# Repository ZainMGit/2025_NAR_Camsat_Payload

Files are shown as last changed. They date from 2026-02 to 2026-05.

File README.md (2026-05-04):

# 2025_NAR_CanSat_Payload
Download KiCAD_Camsat_PCB as a zip file and then open the project file within KiCAD to get the most up to date version of the pcb.

microsd pin orientation: 
-top view with pins pointing towards person and L to R- 
GND, VCC, MISO, MOSI, Sck, cs

9dof board
black wire - GND
Red - 3.3v 
blue- SDA
Yellow - SCL
order: BlaRBY

humidity - 
L to R with pins facing south
-GND, VCC, Signal

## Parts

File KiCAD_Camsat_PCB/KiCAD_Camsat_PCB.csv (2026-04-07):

Reference | Qty | Value | DNP | Exclude from BOM | Exclude from Board | Footprint | Datasheet
ADDR0 | 1 | JUMPER-SMT_3_1-NC_TRACE_SILK |  |  |  | KiCAD_Camsat_PCB:SMT-JUMPER_3_1-NC_TRACE_SILK
C1,C2,C26 | 3 | 2u2 |  |  |  | e-radionica.com footprinti:0603C
C3,C4 | 2 | 10uF |  |  |  | KiCAD_Camsat_PCB:0805-NO
C5,C6 | 2 | 0.1uF |  |  |  | KiCAD_Camsat_PCB:0603
C7,C18,C19,C21 | 4 | 100n |  |  |  | e-radionica.com footprinti:0603C
C8,C9,C13,C16,C20,C25 | 6 | 100nF |  |  |  | Capacitor_SMD:C_0603_1608Metric
C10,C12 | 2 | 10uF |  |  |  | Capacitor_SMD:C_0805_2012Metric
C11 | 1 | 4.7uF |  |  |  | Capacitor_SMD:C_0805_2012Metric
C17 | 1 | 22uF |  |  |  | Capacitor_SMD:C_1206_3216Metric
D1 | 1 | RED |  |  |  | KiCAD_Camsat_PCB:LED-0603
D2 | 1 | 1N4148 |  |  |  | KiCAD_Camsat_PCB:SOD-323
D3,D4,D9 | 3 | LESD5D5.0CT1G |  |  |  | Diode_SMD:D_SOD-523
I2C_PU0 | 1 | S_MODE |  |  |  | KiCAD_Camsat_PCB:SMT-JUMPER_3_2-NC_TRACE_SILK
J3 | 1 | 105017-0001 |  |  |  | Connector_USB:USB_Micro-B_Molex-105017-0001
J4 | 1 | 210-1S-1*3Ppin Gold-plated |  |  |  | Connector_PinHeader_2.54mm:PinHeader_1x03_P2.54mm_Vertical
J5 | 1 | DZ127R-11-02-25 |  |  |  | Connector_PinHeader_1.27mm:PinHeader_1x02_P1.27mm_Vertical
JP1 | 1 | SMD_JUMPER |  |  |  | e-radionica.com footprinti:SMD_JUMPER
JP9 | 1 | SMD-JUMPER-CONNECTED_TRACE_SLODERMASK |  |  |  | e-radionica.com footprinti:SMD-JUMPER-CONNECTED_TRACE_SLODERMASK
K1 | 1 | HYC77-TF09-200 |  |  |  | e-radionica.com footprinti:HYC77-TF09-200
LED0,SCX0,SDX0 | 3 | JUMPER-SMT_2_NC_TRACE_SILK |  |  |  | KiCAD_Camsat_PCB:SMT-JUMPER_2_NC_TRACE_SILK
LED1 | 1 | 0805G (Green) |  |  |  | LED_SMD:LED_0805_2012Metric
LED2 | 1 | FC-2012HRK-620D |  |  |  | LED_SMD:LED_0805_2012Metric
Q1,Q8 | 2 | 2N7002T-7-F |  |  |  | Package_TO_SOT_SMD:SOT-523
Q2,Q9 | 2 | SS8050-G_C164885 |  |  |  | Package_TO_SOT_SMD:SOT-23
Q3,Q4 | 2 | BSS138 |  |  |  | KiCAD_Camsat_PCB:SOT23-WIDE
R1 | 1 | 10k |  |  |  | e-radionica.com footprinti:0603R
R2,R25 | 2 | 2.2k |  |  |  | KiCAD_Camsat_PCB:0603
R3,R5,R6 | 3 | 10k |  |  |  | KiCAD_Camsat_PCB:0603
R4 | 1 | 1k |  |  |  | KiCAD_Camsat_PCB:0603
R7,R8,R26,R27 | 4 | 10K |  |  |  | KiCAD_Camsat_PCB:0805-NO
R9 | 1 | 10K |  |  |  | KiCAD_Camsat_PCB:_0805MP
R10 | 1 | 10k |  |  |  | Resistor_SMD:R_0805_2012Metric | ~
R11 | 1 | 47.5kΩ |  |  |  | Resistor_SMD:R_0805_2012Metric
R12 | 1 | 22.1kΩ |  |  |  | Resistor_SMD:R_0805_2012Metric
R13,R17,R18,R21,R22 | 5 | 10kΩ |  |  |  | Resistor_SMD:R_0805_2012Metric
R14,R24 | 2 | 22Ω |  |  |  | Resistor_SMD:R_0805_2012Metric
R15 | 1 | 5.1kΩ |  |  |  | Resistor_SMD:R_0805_2012Metric
R16 | 1 | 560Ω |  |  |  | Resistor_SMD:R_0805_2012Metric
R19,R20 | 2 | 0Ω |  |  |  | Resistor_SMD:R_0805_2012Metric
R23,R29 | 2 | 1kΩ |  |  |  | Resistor_SMD:R_0805_2012Metric
SW1,SW2 | 2 | PTS645SH50SMTR92LFS |  |  |  | Button_Switch_SMD:SW_SPST_PTS645Sx43SMTR92
U1 | 1 | ISM330DHCX |  |  |  | KiCAD_Camsat_PCB:LGA-14L
U2 | 1 | MIC5225-3.3 |  |  |  | KiCAD_Camsat_PCB:SOT23-5
U3 | 1 | SE5218 |  |  |  | e-radionica.com footprinti:SOT-23-5
U4 | 1 | TXB0104QPWRQ1 |  |  |  | e-radionica.com footprinti:TXB0104QPWRQ1
U5 | 1 | DHT11 |  |  |  | Sensor:Aosong_DHT11_5.5x12.0_P2.54mm | http://akizukidenshi.com/download/ds/aosong/DHT11.pdf
U7 | 1 | AMS1117-3.3_C347222 |  |  |  | Package_TO_SOT_SMD:SOT-223-3_TabPin2
U8 | 1 | ESP32-WROOM-32E(8MB) |  |  |  | PCM_Espressif:ESP32-WROOM-32E
U9 | 1 | CP2102N-A02-GQFN28R |  |  |  | Package_DFN_QFN:QFN-28-1EP_5x5mm_P0.5mm_EP3.35x3.35mm
U10 | 1 | BME280 |  |  |  | KiCAD_Camsat_PCB:BME280

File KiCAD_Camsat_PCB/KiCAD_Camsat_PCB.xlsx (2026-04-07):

Prj: | KiCAD_Camsat_PCB.csv |  |  |  | Board Qty: | 100
Co.: |  |  |  |  | Unit Cost: | $0.00
Prj date: | 2026-04-01 00:43:22 (file) |  |  |  | Total Cost: | $0.00
$ date: | 2026-04-01 00:51:03
Global Part Info
Refs | Value | Footprint | Manf# | Qty | Unit$ | Ext$
0.1uF0,LESD5D5.0CT1G,BSS138,1kÎ©0,47.5kÎ©,22Î©,5.1kÎ©0,0Î©0,PTS645SH50SMTR92LFS | ??? | ??? | 2 | 900
100n,100nF,10kÎ© | ??? | ??? | 4 | 300
2u2,JUMPERSMT_2_NC_TRACE_SILK0 | ??? | ??? | 3 | 200
JUMPERSMT_3_1NC_TRACE_SILK0,10uF,22uF,4.7uF0,RED0,1N4148,S_MODE0,105017-1,210-1S-13Ppin,Goldplated0,DZ127R-11-02-25,SMDJUMPERCONNECTED_TRACE_SLODERMASK0,SMD_JUMPER0,0805G,Green0,FC2012HRK620D0,2N7002T-7-F,SS8050-SS164885,10k,2.2k0,1k0,10K,22.1kÎ©,560Î©,ISM330DHCX,BME280,SE5218,TXB0104QPWRQ1,DHT11,AMS1117-AMS347222,ESP32-WROOM-32E8MB,CP2102N-A02-GQFN28R | ??? | ??? | 1 | 50297200
KiCost® v1.1.20

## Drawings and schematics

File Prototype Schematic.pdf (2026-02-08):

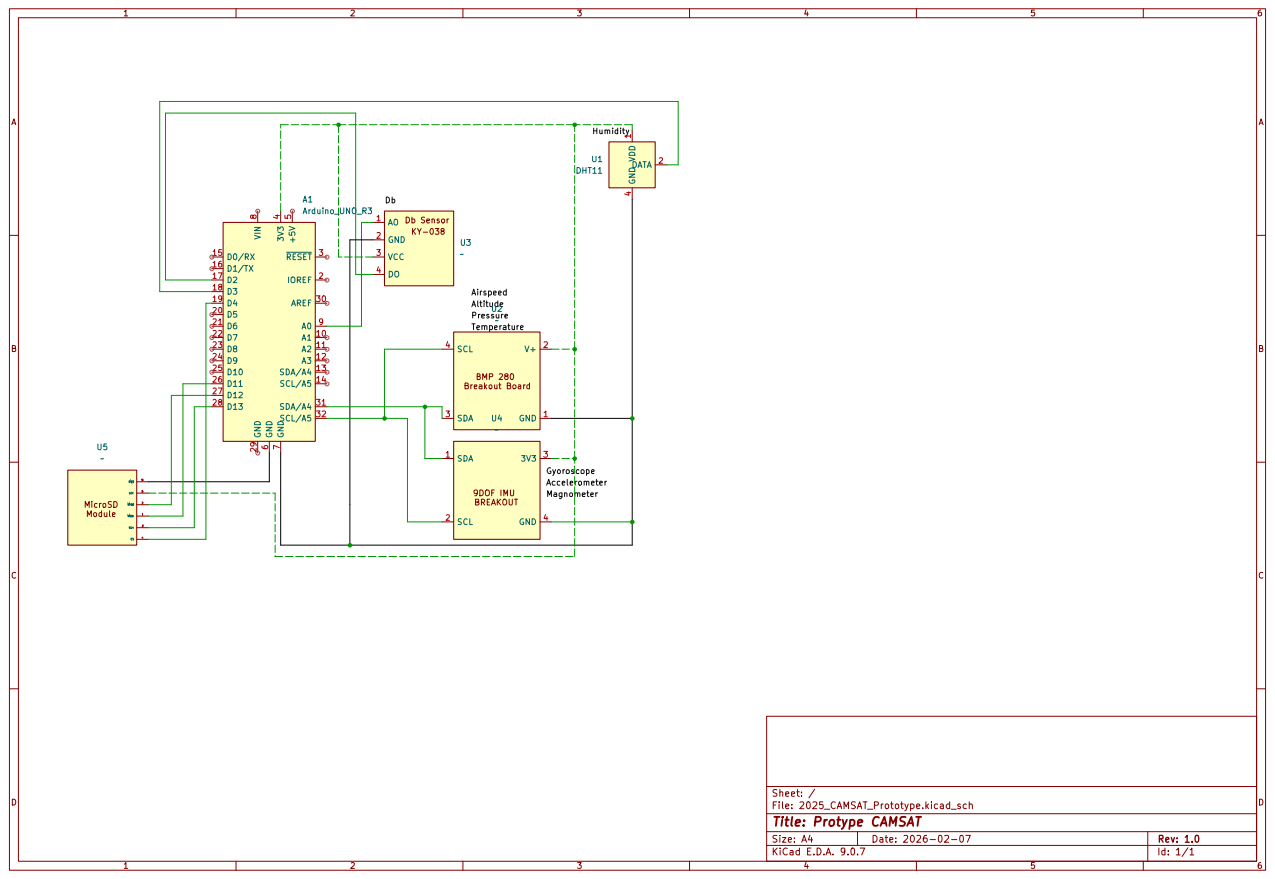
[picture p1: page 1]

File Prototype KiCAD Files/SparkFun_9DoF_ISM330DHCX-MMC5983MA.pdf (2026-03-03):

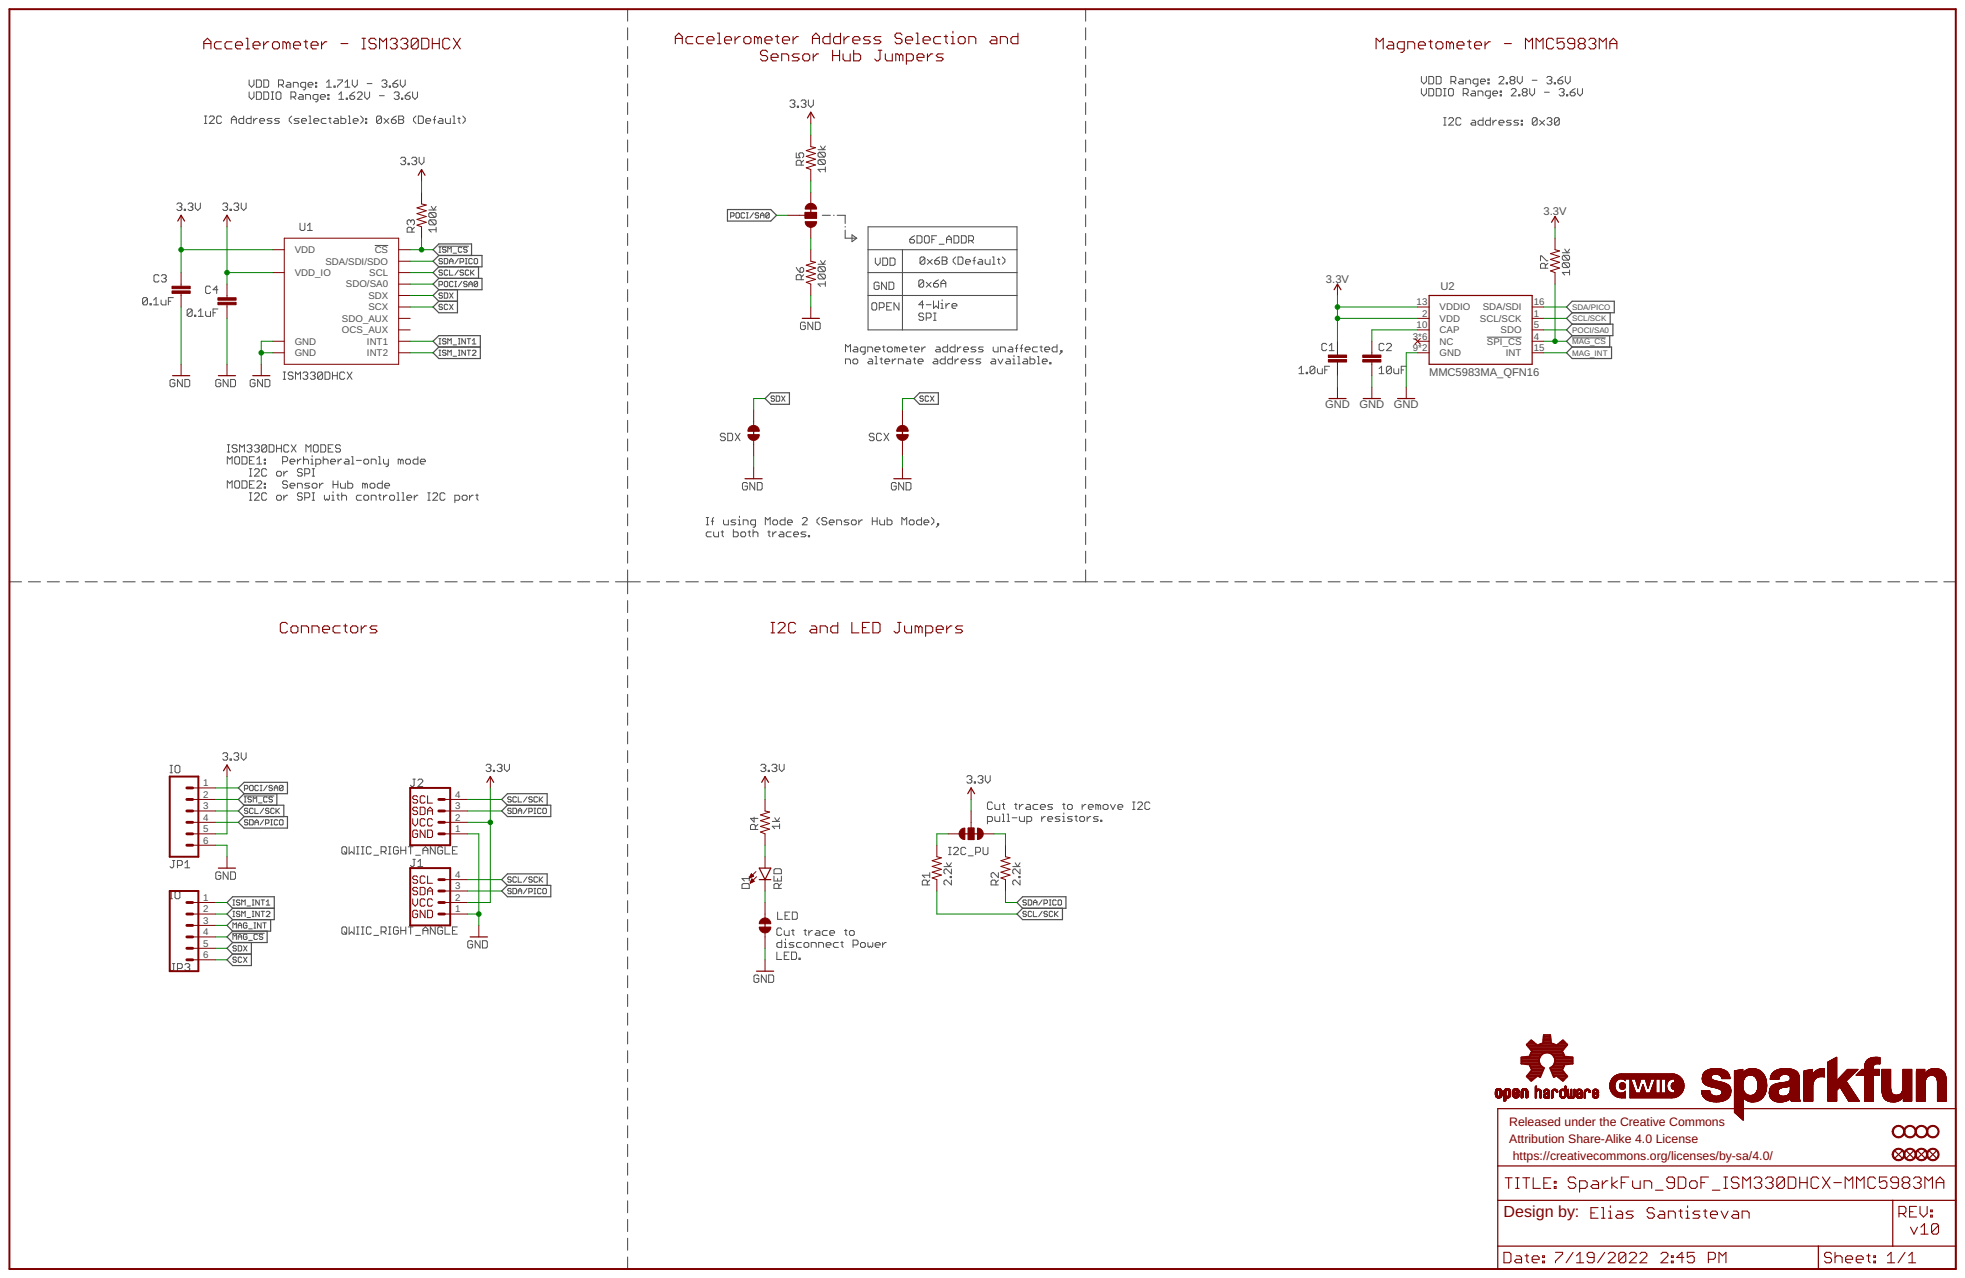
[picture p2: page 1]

Released under the Creative Commons Attribution Share-Alike 4.0 License

https://creativecommons.org/licenses/by-sa/4.0/ Design by:

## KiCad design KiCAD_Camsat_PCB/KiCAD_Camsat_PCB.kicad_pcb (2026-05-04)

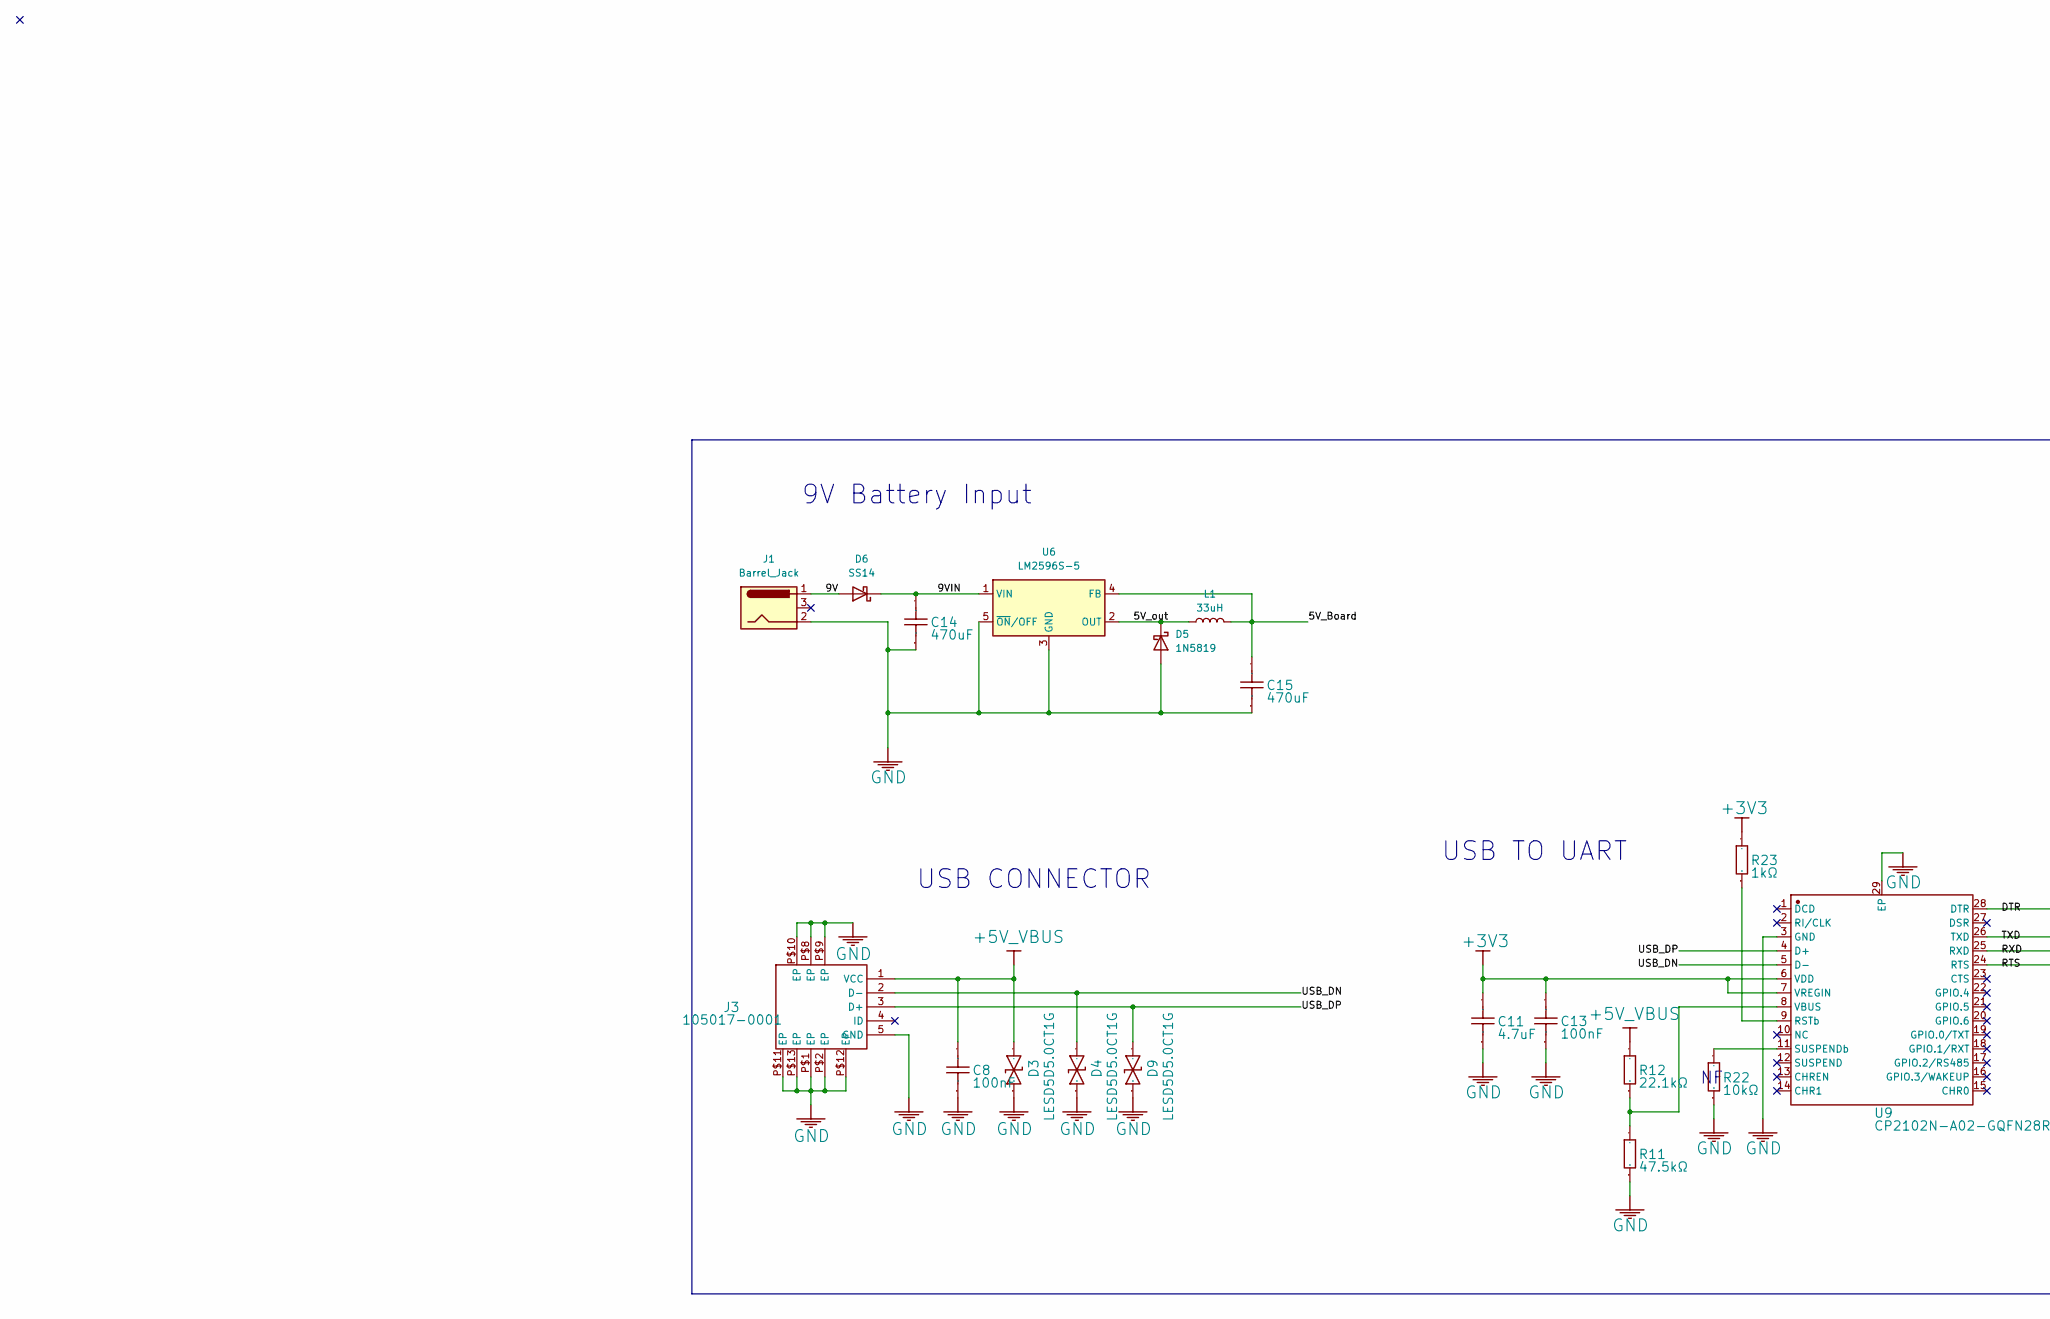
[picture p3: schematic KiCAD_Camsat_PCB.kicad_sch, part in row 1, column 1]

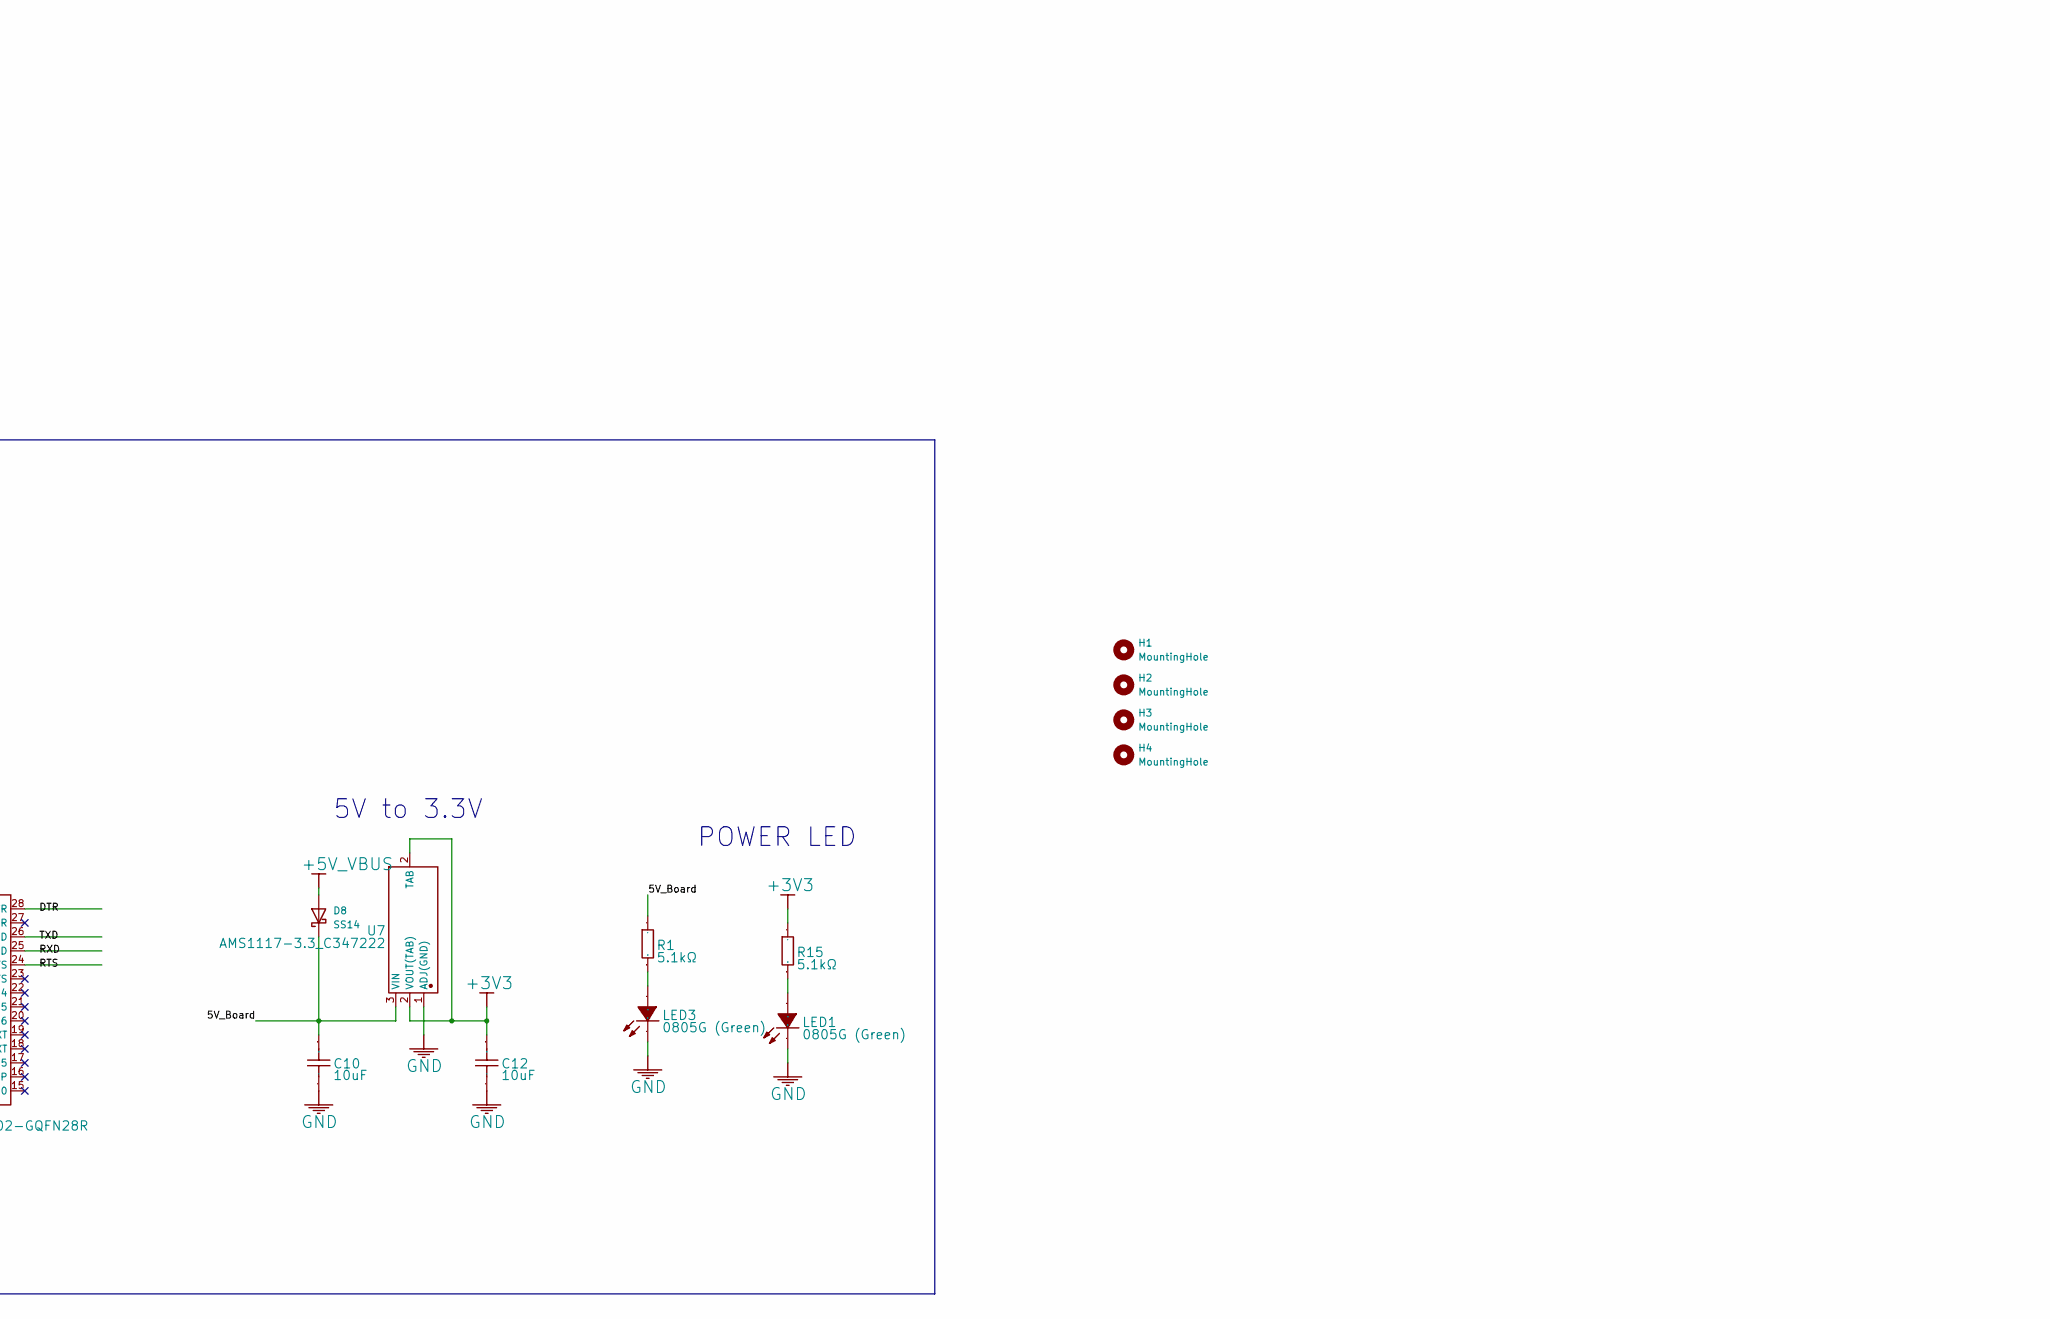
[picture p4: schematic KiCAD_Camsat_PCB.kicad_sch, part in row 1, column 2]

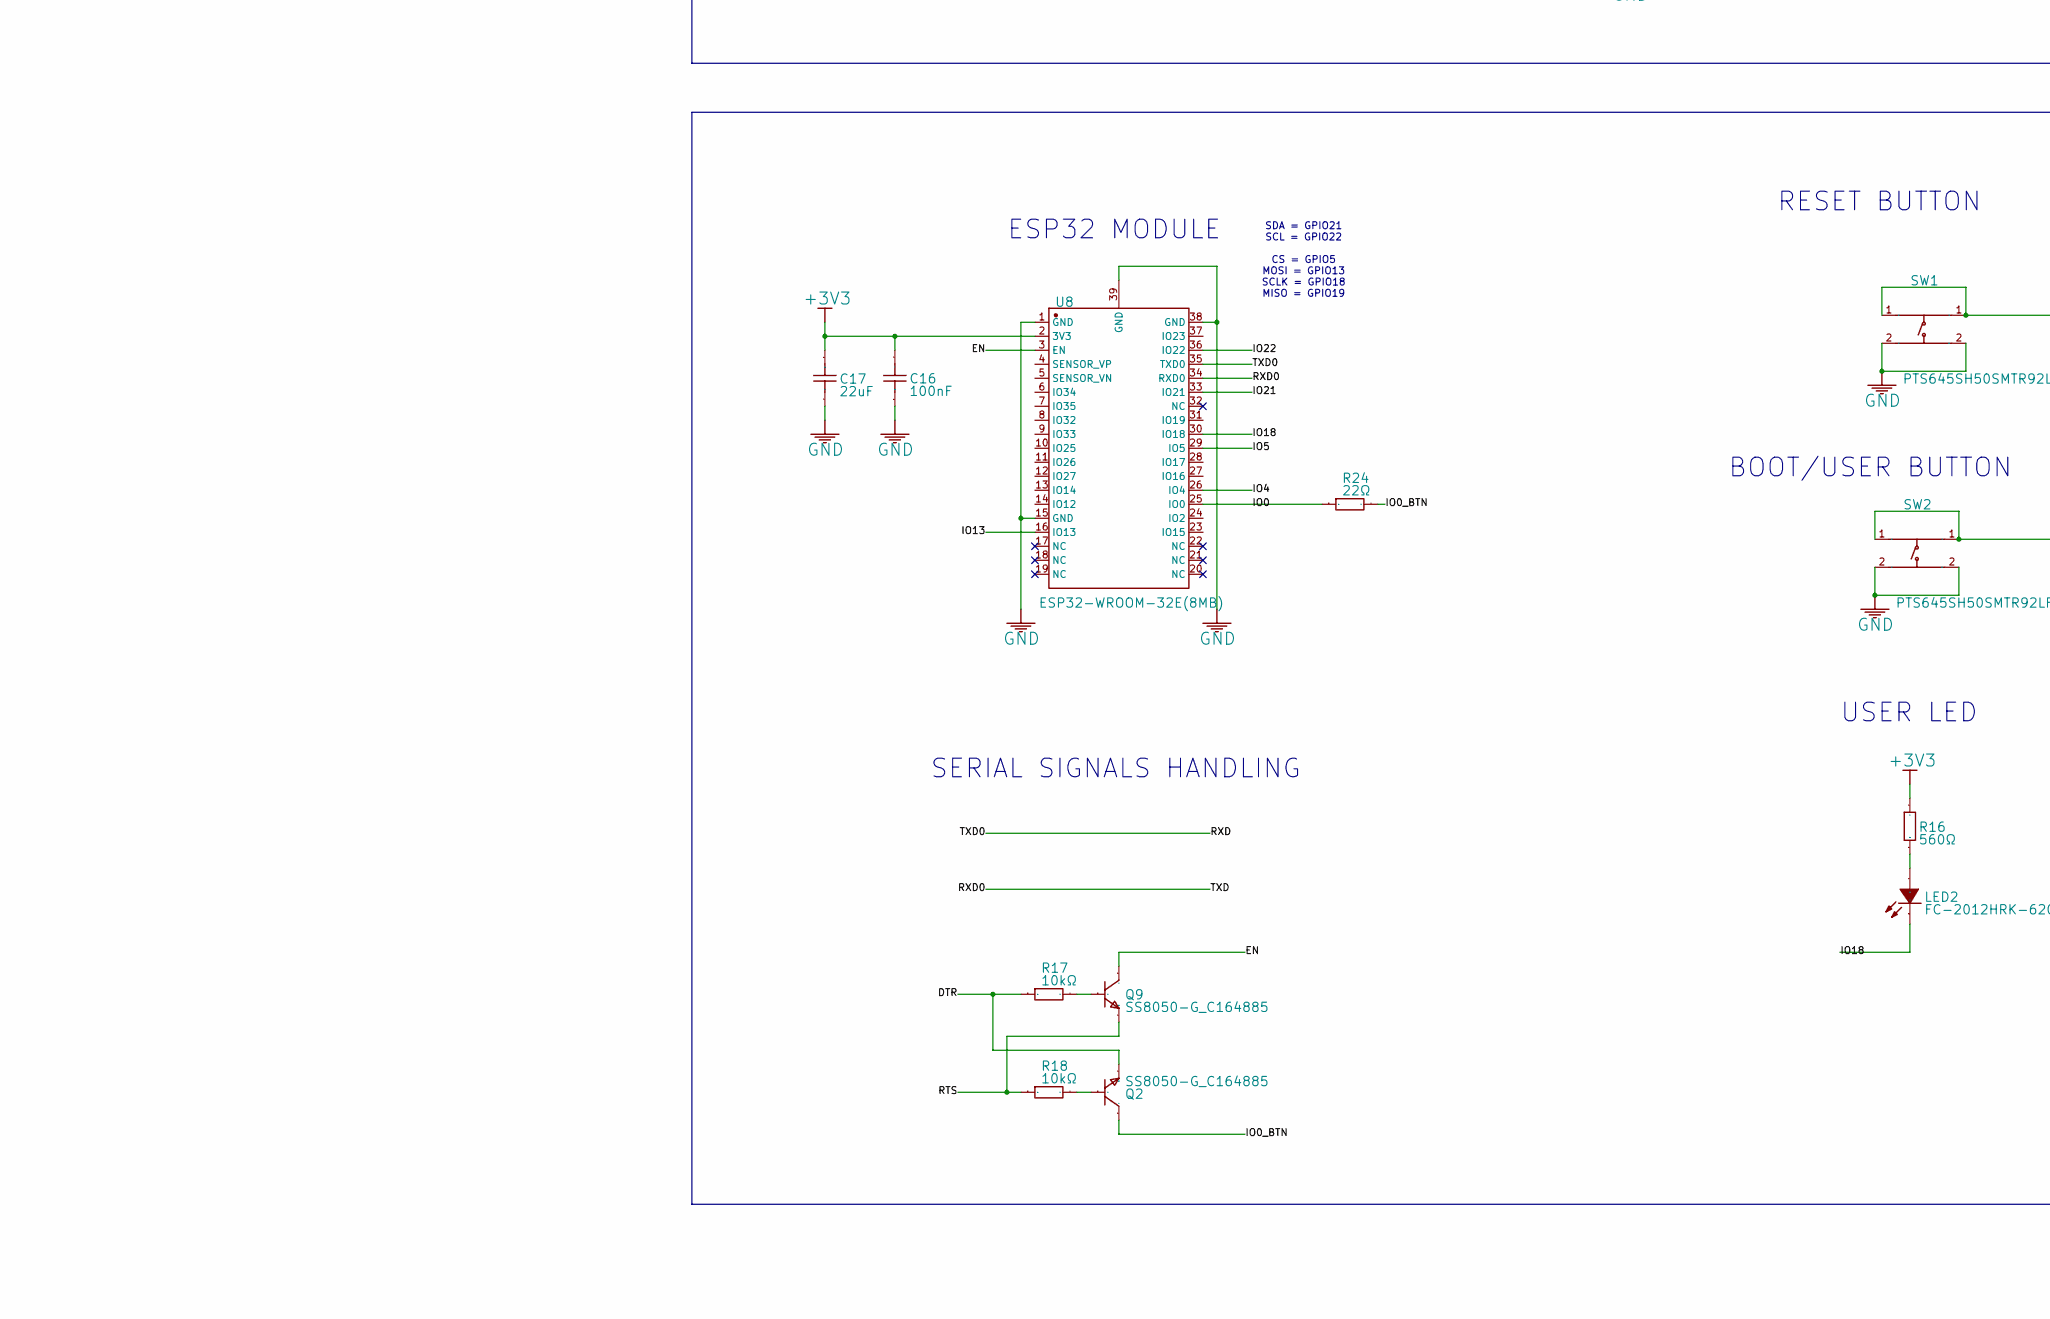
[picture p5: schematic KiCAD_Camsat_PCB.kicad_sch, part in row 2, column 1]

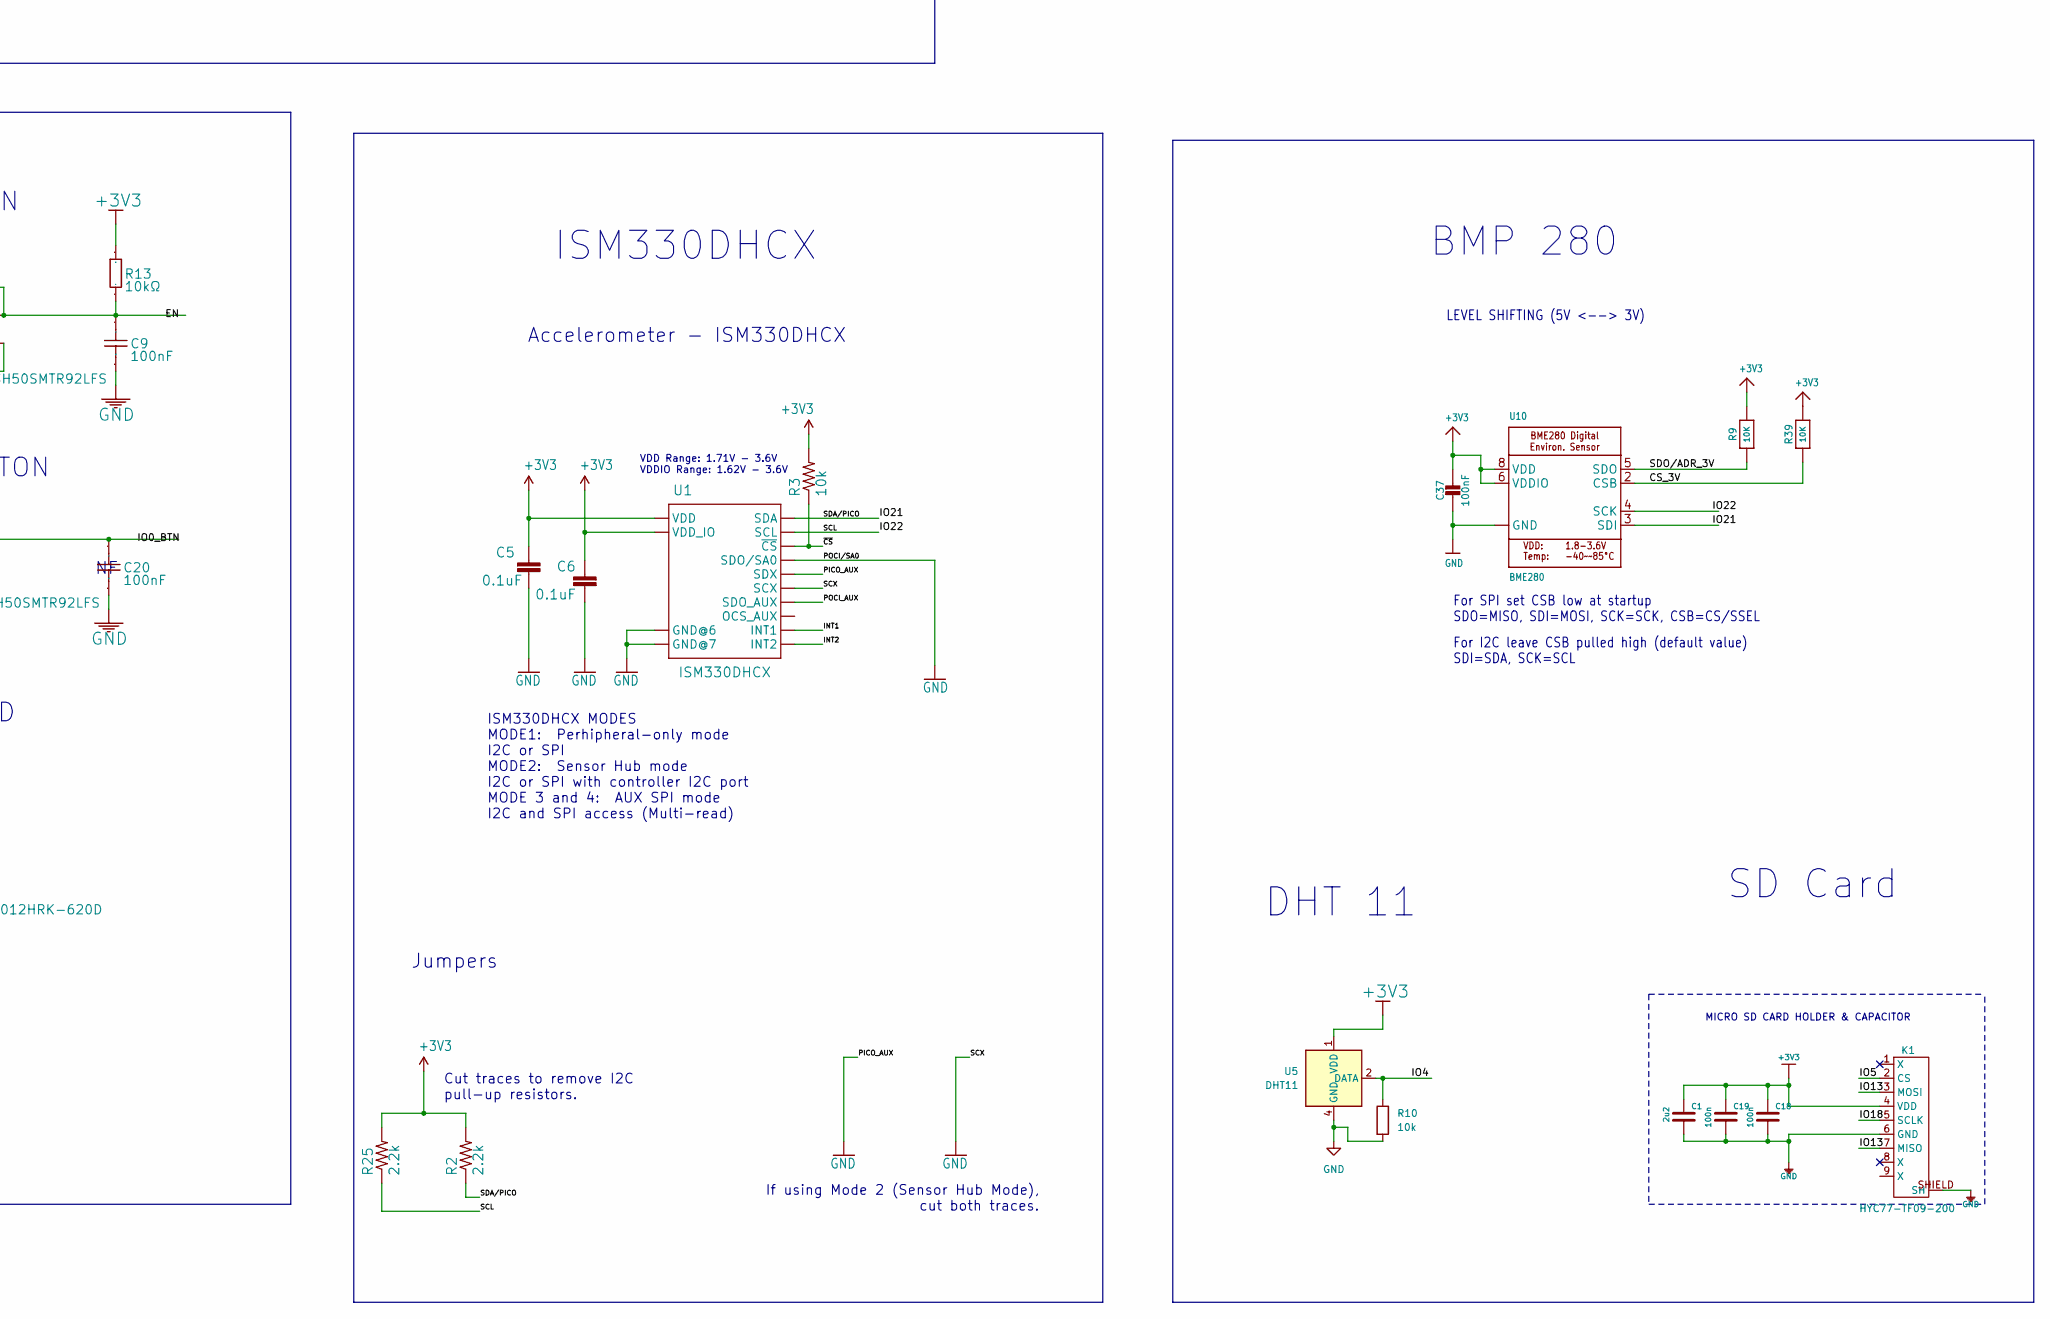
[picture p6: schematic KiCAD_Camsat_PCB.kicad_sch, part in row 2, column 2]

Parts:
C1: 2u2; C_0603_1608Metric
C5, C6: 0.1uF; C_0603_1608Metric
C8, C9, C13, C16, C20: 100nF; C_0603_1608Metric; Manufacturer Part CL05B104KO5NNNC
C10, C12: 10uF; C_0805_2012Metric; Manufacturer Part CL05A106MP5NUNC
C11: 4.7uF; C_0805_2012Metric; Manufacturer Part CL05A475KP5NRNC
C14, C15: 470uF; C_0603_1608Metric; Manufacturer Part CL05B104KO5NNNC
C17: 22uF; C_1206_3216Metric; Manufacturer Part CL21A226MAYNNNE
C18, C19: 100n; C_0603_1608Metric
C37: 100nF; C_0603_1608Metric
D3, D4, D9: LESD5D5.0CT1G; D_SOD-523; Manufacturer Part LESD5D5.0CT1G
D5: 1N5819; D_DO-41_SOD81_P10.16mm_Horizontal
D6, D8: SS14; D_SMA
H1, H2, H3, H4: MountingHole; MountingHole_3mm
J1: Barrel_Jack; BarrelJack_CUI_PJ-102AH_Horizontal
J3: 105017-0001; MOLEX_105017-0001; Manufacturer Part 1050170001
K1: HYC77-TF09-200; MICROSD-HYC77-TF09-200
L1: 33uH; L_Bourns_SRN8040TA
LED1, LED3: 0805G (Green); LED_0805_2012Metric; Manufacturer Part KT-0805G
LED2: FC-2012HRK-620D; LED_0805_2012Metric; Manufacturer Part NCD0805R1
Q2, Q9: SS8050-G_C164885; SOT-23; Manufacturer Part SS8050-G(RANGE:200-350)
R1, R15: 5.1kΩ; R_0805_2012Metric; Manufacturer Part 0402WGF5101TCE
R2, R25: 2.2k; R_0805_2012Metric
R3, R10: 10k; R_0805_2012Metric
R9, R39: 10K; R_0805_2012Metric
R11: 47.5kΩ; R_0805_2012Metric; Manufacturer Part 0402WGF4752TCE
R12: 22.1kΩ; R_0805_2012Metric; Manufacturer Part 0402WGF2212TCE
R13, R17, R18, R22: 10kΩ; R_0805_2012Metric; Manufacturer Part 0402WGF1002TCE
R16: 560Ω; R_0805_2012Metric; Manufacturer Part 0402WGF5600TCE
R23: 1kΩ; R_0805_2012Metric; Manufacturer Part 0402WGF1001TCE
R24: 22Ω; R_0805_2012Metric; Manufacturer Part 0402WGF220JTCE
SW1, SW2: PTS645SH50SMTR92LFS; SW_SPST_PTS645Sx43SMTR92; Manufacturer Part PTS645SH50SMTR92LFS
U1: ISM330DHCX; PQFN50P250X300X86-14N
U5: DHT11; Aosong_DHT11_5.5x12.0_P2.54mm
U6: LM2596S-5; TO-263-5_TabPin3
U7: AMS1117-3.3_C347222; SOT-223-3_TabPin2; Manufacturer Part AMS1117-3.3
U8: ESP32-WROOM-32E(8MB); ESP32-WROOM-32E; Manufacturer Part ESP32-WROOM-32E-N8
U9: CP2102N-A02-GQFN28R; QFN-28-1EP_5x5mm_P0.5mm_EP3.35x3.35mm; Manufacturer Part CP2102N-A02-GQFN28R
U10: BME280; PSON65P250X250X100-8N

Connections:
+3V3: C1.2, C5.1, C6.1, C11.2, C12.1, C13.2, C16.2, C17.1, C18.2, C19.2, C37.1, K1.4 (VDD), R2.2, R3.2, R9.2, R13.1, R15.2, R16.2, R23.2, R25.2, R39.2, U1.5 (VDD_IO), U1.8 (VDD), U5.1 (VDD), U7.2 (VOUT(TAB)), U8.2 (3V3), U9.6 (VDD), U9.7 (VREGIN), U10.6 (VDDIO), U10.8 (VDD)
+5V_VBUS: C8.2, D3.2, D8.2 (A), J3.1 (VCC), R12.2
/5V_Board: C10.1, C15.2, D8.1 (K), L1.2, R1.2, U6.4 (FB), U7.3 (VIN)
/5V_out: D5.1 (K), L1.1, U6.2 (OUT)
/9V: D6.2 (A), J1.1
/9VIN: C14.2, D6.1 (K), U6.1 (VIN)
/CS_3V: R39.1, U10.2 (CSB)
/DTR: Q2.2 (E), R17.1, U9.28 (DTR)
/EN: C9.2, Q9.3 (C), R13.2, SW1.1, U8.3 (EN); also elsewhere on the board
/INT1: U1.4 (INT1)
/INT2: U1.9 (INT2)
/IO0: R24.1, U8.25 (IO0)
/IO0_BTN: C20.2, Q2.3 (C), R24.2, SW2.1; also elsewhere on the board
/IO4: R10.1, U5.2 (DATA), U8.26 (IO4)
/IO5: K1.2 (CS), U8.29 (IO5)
/IO13: K1.3 (MOSI), K1.7 (MISO), U8.16 (IO13)
/IO18: K1.5 (SCLK), LED2.1 (-), U8.30 (IO18); also elsewhere on the board
/IO21: R2.1, U1.14 (SDA), U8.33 (IO21), U10.3 (SDI)
/IO22: R25.1, U1.13 (SCL), U8.36 (IO22), U10.4 (SCK)
/POCI_AUX: U1.11 (SDO_AUX)
/RTS: Q9.2 (E), R18.1, U9.24 (RTS)
/RXD: U8.35 (TXD0), U9.25 (RXD)
/RXD0: U8.34 (RXD0), U9.26 (TXD)
/SDO/ADR_3V: R9.1, U10.5 (SDO)
/USB_DN: D4.2, J3.2 (D-), U9.5 (D-)
/USB_DP: D9.2, J3.3 (D+), U9.4 (D+)
/~CS: R3.1, U1.12 (~CS)
GND: C1.1, C5.2, C6.2, C8.1, C9.1, C10.2, C11.1, C12.2, C13.1, C14.1, C15.1, C16.1, C17.2, C18.1, C19.1, C20.1, C37.2, D3.1, D4.1, D5.2 (A), D9.1, J1.2, J3.5 (GND), J3.P$1 (EP), J3.P$2 (EP), J3.P$8 (EP), J3.P$9 (EP), J3.P$10 (EP), J3.P$11 (EP), J3.P$12 (EP), J3.P$13 (EP), K1.6 (GND), K1.SHIELD (SH), LED1.2 (K), LED3.2 (K), R10.2, R11.1, R22.1, SW1.2 (3), SW2.2 (3), U1.1 (SDO/SA0), U1.2 (SDX), U1.3 (SCX), U1.6 (GND@6), U1.7 (GND@7), U5.4 (GND), U6.3 (GND), U6.5 (~ON/OFF), U7.1 (ADJ(GND)), U8.1 (GND), U8.15 (GND), U8.38 (GND), U8.39 (GND), U9.3 (GND), U9.29 (EP), U10.1 (GND), U10.7 (GND); also elsewhere on the board
unnamed: LED1.1 (A), R15.1
unnamed 29: LED2.2 (+), R16.1; also elsewhere on the board
unnamed: LED3.1 (A), R1.1
unnamed: Q2.1 (B), R18.2
unnamed: Q9.1 (B), R17.2
unnamed: R23.1, U9.9 (RSTb)
unnamed: R22.2, U9.11 (SUSPENDb)
unnamed: R11.2, R12.1, U9.8 (VBUS)

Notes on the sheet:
ESP32 MODULE
SDA = GPIO21 SCL = GPIO22 CS = GPIO5 MOSI = GPIO13 SCLK = GPIO18 MISO = GPIO19
DHT 11
SD Card
POWER LED
BOOT/USER BUTTON
VDD Range: 1.71V - 3.6V VDDIO Range: 1.62V - 3.6V
9V Battery Input
MICRO SD CARD HOLDER & CAPACITOR
ISM330DHCX MODES MODE1: Perhipheral-only mode I2C or SPI MODE2: Sensor Hub mode I2C or SPI with controller I2C port MODE 3 and 4: AUX SPI mode I2C and SPI access (Multi-read)
USB CONNECTOR
SERIAL SIGNALS HANDLING
For I2C leave CSB pulled high (default value) SDI=SDA, SCK=SCL
USB TO UART
USER LED
5V to 3.3V
For SPI set CSB low at startup SDO=MISO, SDI=MOSI, SCK=SCK, CSB=CS/SSEL
LEVEL SHIFTING (5V <--> 3V)
BMP 280
ISM330DHCX
Jumpers
RESET BUTTON
Cut traces to remove I2C pull-up resistors.
Accelerometer - ISM330DHCX
If using Mode 2 (Sensor Hub Mode), cut both traces.

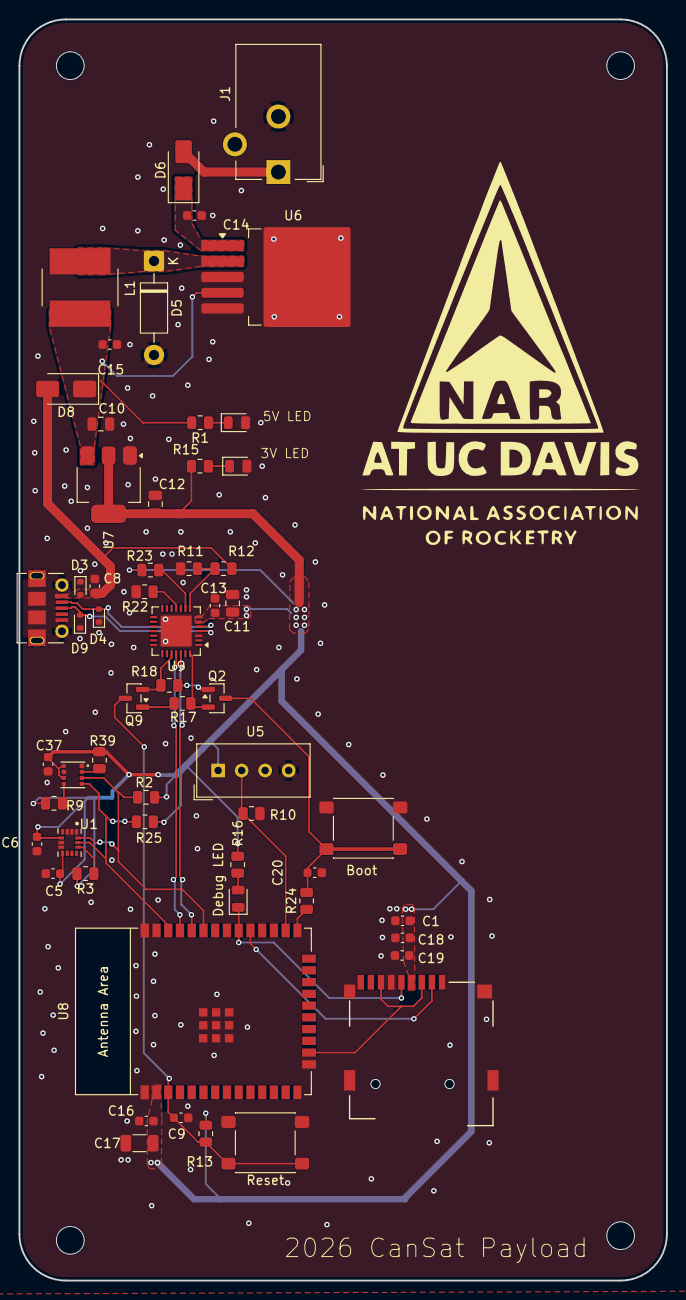
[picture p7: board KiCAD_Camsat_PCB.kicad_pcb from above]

Board: 2 copper layers, 70.0 x 136.3 mm, 62 parts (0 on the bottom side), 33 nets.

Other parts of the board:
Boot: PTS645SH50SMTR92LFS; SW_SPST_PTS645Sx43SMTR92
Debug LED: FC-2012HRK-620D; LED_0805_2012Metric
Reset: PTS645SH50SMTR92LFS; SW_SPST_PTS645Sx43SMTR92

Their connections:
/EN: Reset.1; also elsewhere on the board
/IO0_BTN: Boot.1; also elsewhere on the board
/IO18: Debug LED.1 (-); also elsewhere on the board
GND: Boot.2 (3), Reset.2 (3); also elsewhere on the board
unnamed 29: Debug LED.2 (+); also elsewhere on the board

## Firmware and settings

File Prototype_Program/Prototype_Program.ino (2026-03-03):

#include <DHT11.h>
#include <SPI.h>
#include <SD.h>

// Pin definitions
#define DHTPIN 3
#define SD_CS 4   // Chip select pin for SD card


DHT11 dht11(DHTPIN);


File myFile, myFile2; 

const int DB_Sensor = A0;

void setup() { 
  Serial.begin(9600);

  // Wait for Serial (needed for some boards like Leonardo)
  while (!Serial) {
    ;
  }

  Serial.print("Initializing SD card...");

  if (!SD.begin(SD_CS)) {
    Serial.println("initialization failed!");
    while (1);  // Stop here if SD fails
  }

  Serial.println("initialization done.");

  myFile = SD.open("test.txt", FILE_WRITE);

  if (myFile) {
    Serial.println("Writing to test.txt...");

    myFile.println("This is a test file :)");
    myFile.println("testing 1, 2, 3.");

    for (int i = 0; i < 20; i++) {
      myFile.println(i);
    }

    myFile.close();
    Serial.println("done.");
  } else {
    // If the file didn't open, print an error
    Serial.println("error opening test.txt");
  }
}

void loop() {
  int temperature = 0;
  int humidity = 0;

  // Read DHT11 data
  int result = dht11.readTemperatureHumidity(temperature, humidity);

  if (result == 0) {  // Successful read
    Serial.print("Temp: ");
    Serial.print(temperature);
    Serial.print(" C\tHumidity: ");
    Serial.print(humidity);
    Serial.println(" %");
  } else {
    Serial.println("Failed to read from DHT11");
  }

  myFile = SD.open("test.txt", FILE_WRITE);

  if (myFile) {

    myFile.println("Starting Humidity readings");
    myFile.println("Temp: ");
    myFile.print(temperature);
    Serial.println(" C\tHumidity: ");
    Serial.print(humidity);
    Serial.print(" %");

    myFile.close();


  delay(1000);
}
}

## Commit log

2026-02-08 Add KiCAD Project
    [2025_CAMSAT_Prototype.kicad_pcb, 2025_CAMSAT_Prototype.kicad_sch]
2026-02-08 Create Prototype Schematic.pdf
2026-02-10 Create Prototype_program
2026-02-10 Update README.md
    description of sensor pins with pins facing south
2026-03-03 Pin Change
2026-03-27 Payload_PCB files
    [Adafruit BMP280 (1).sch, KiCAD_Camsat_PCB.kicad_pcb, KiCAD_Camsat_PCB.kicad_sch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]
2026-04-01 Payload pcb updates
    [KiCAD_Camsat_PCB.kicad_sch]
2026-04-01 Schematic updates
    [KiCAD_Camsat_PCB.kicad_sch]
2026-04-07 9V connector
    [KiCAD_Camsat_PCB.csv, KiCAD_Camsat_PCB.kicad_pcb, KiCAD_Camsat_PCB.kicad_sch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]
2026-04-07 Footprint Updates
    [KiCAD_Camsat_PCB.kicad_pcb, KiCAD_Camsat_PCB.kicad_sch]
2026-04-07 All Footprints completed
    [KiCAD_Camsat_PCB.kicad_sch]
2026-04-09 schemaric errors
    [KiCAD_Camsat_PCB.kicad_pcb, KiCAD_Camsat_PCB.kicad_sch]
2026-04-09 Power selection
    [KiCAD_Camsat_PCB.kicad_sch]
2026-04-14 Schematic Ready
    [KiCAD_Camsat_PCB.kicad_sch]
2026-04-14 New PCB design
    [KiCAD_Camsat_PCB.kicad_pcb]
2026-04-25 PCB changes
    [KiCAD_Camsat_PCB.kicad_pcb, freerouting.dsn, temp-freerouting.dsn]
2026-04-29 new changes
    [KiCAD_Camsat_PCB.kicad_pcb, KiCAD_Camsat_PCB.kicad_sch, freerouting.dsn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]
2026-04-29 DRC update
    [KiCAD_Camsat_PCB.kicad_pcb]
2026-04-29 file organization
    [2025_CAMSAT_Prototype.kicad_pcb, 2025_CAMSAT_Prototype.kicad_sch, Adafruit BMP280 (1).sch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]
2026-04-30 Create wroom_v1 (2).kicad_sch
    [wroom_v1 (2).kicad_sch]
2026-04-30 Layout Revision
    Removed unnecessary nets.
    Added nets for copper pours.
    Removed some non-critical components from schematic.
    Still needs some extra vias and adjusting silkscreen.
    [KiCAD_Camsat_PCB.kicad_pcb, KiCAD_Camsat_PCB.kicad_sch]
2026-05-01 PCB Board Updates
    - Board Dimensions changed to 70mm width
    - Descriptive Silkscreen values added
    [KiCAD_Camsat_PCB.kicad_pcb]
2026-05-01 More silkscreen updates
    [KiCAD_Camsat_PCB.kicad_pcb]
2026-05-01 silkscreen update
2026-05-02 Mounting Hole Size Changes
    [KiCAD_Camsat_PCB.kicad_pcb, KiCAD_Camsat_PCB.kicad_sch]
2026-05-04 Final Design Changes
    - Updated Silkscreen
    - small route updates
    [KiCAD_Camsat_PCB.kicad_pcb]

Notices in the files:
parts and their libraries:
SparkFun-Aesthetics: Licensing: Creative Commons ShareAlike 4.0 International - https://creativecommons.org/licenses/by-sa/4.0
